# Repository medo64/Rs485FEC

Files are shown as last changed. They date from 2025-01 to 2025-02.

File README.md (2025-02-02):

[RS-485 Framework Expansion Card](https://medo64.com/rs485framecard/)
=====================================================================

This Framework laptop expansion card will show up on your system as a serial
device and allow for non-isolated RS-485 communication up to 3,000,800 baud
rate.

Please note that this card is using automatic transmit control and is 120Ω
terminated.

## Pinout

To connect to this board, one has to use a 4-pin JST XH connector. The following
table represents the pinout, pin 1 being on the left as looking into the
expansion card.

| # | Ref | Description |
|--:|-----|---|
| 1 | GND | Ground connection |
| 2 | A | Negative (low for logic 1 and high for logic 0) |
| 3 | B | Positive (high for logic 1 and low for logic 0) |
| 4 | 5V  | 100 mA power supply |

As power consumption is low, wires can be almost any AWG. I would recommend
using 24 AWG wire 0.25 mm² as they allow for greater compatibility with other
connectors.

## Supported Speeds

This board employs the FT232R as its UART chip, and consequently, it supports
all the baud rates this chip [can handle](https://ftdichip.com/Documents/AppNotes/AN232B-05_BaudRates.pdf)
up to 500,000 baud which is the limit of isolator chip used. The table below
lists the standard baud rates.

| Baud rate | Actual | Error | Divisor |
|---:|---:|---:|---:|
| 300 | 300 | 0.00% |  10000.000 |
| 600 | 600 | 0.00% | 5000.000 |
| 1,200 | 1,200 | 0.00% | 2500.000 |
| 1,800 | 1,800 | 0.00% | 1666.625 |
| 2,400 | 2,400 | 0.00% | 1250.000 |
| 4,800 | 4,800 | 0.00% | 625.000 |
| 7,200 | 7,201 | 0.01% | 416.625 |
| 9,600 | 9,600 | 0.00% | 312.500 |
| 14,400 | 14,406 | 0.04% | 208.250 |
| 19,200 | 19,200 | 0.00% | 156.250 |
| 28,800 | 28,812 | 0.04% | 104.125 |
| 38,400 | 38,400 | 0.00% | 78.125 |
| 57,600 | 57,692 | 0.16% | 52.000 |
| 115,200 | 115,385 | 0.16% | 26.000 |
| 230,400 | 230,769 | 0.16% | 13.000 |
| 460,800 | 461,538 | 0.16% | 6.500 |
| 921,600 | 923,077 | 0.16% | 3.250 |
| 1,000,000 | 1,000,000 | 0.00% | 3.000 |
| 2,000,000 | 2,000,000 | 0.00% | 2.000 |
| 3,000,000 | 3,000,000 | 0.00% | 0.000 |

While rates above this can be set, they are not guaranteed to work.

---
*You can check my blog and other projects at [www.medo64.com](https://www.medo64.com/electronics/).*

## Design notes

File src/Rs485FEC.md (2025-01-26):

### Rs485FEC

#### Parts

|  # | Part | RefDes  | Preferred Part Number |
|---:|---|---|---|
|  1 | C 10nF X7R 16V (0805) | C1 | 399-17617-1-ND |
|  5 | C 100nF X7R 16V (0805) | C2-C6 | 478-5311-1-ND |
|  3 | C 10uF X5R 16V (0805) | C7-C9 | 490-18664-1-ND |
|  1 | D Schottky 30V 800mA [CUS08F30,H3F] (SOD323) | D1 | CUS08F30H3FCT-ND |
|  1 | D TVS SM712 | D2 | SM712-TPMSCT-ND |
|  2 | DS LED (0805) | DS1-DS2 | 475-1415-1-ND |
|  1 | J USB C, plug, straddle 0.8mm | J1 | WM12855-ND |
|  1 | J JST XH Vertical (4w) | J2 | 455-B4B-XH-A-ND |
|  1 | L Ferrite 600R@100Mhz | L1 | 240-2390-1-ND |
|  1 | Q P-MOSFET DMP3099L-13 (SOT23) | Q1 | DMP3099L-13DICT-ND |
|  1 | R 120 0.125W (0805) | R1 | RMCF0805FT120RCT-ND |
|  2 | R 1K 0.125W (0805) | R2-R3 | RMCF0805FT1K00CT-ND |
|  1 | R 5.1K 0.125W (0805) | R4 | RMCF0805FT5K10CT-ND |
|  1 | R 10K 0.125W (0805) | R5 | RMCF0805FT10K0CT-ND |
|  1 | R 75K 0.125W (0805) | R6 | RMCF0805FT75K0CT-ND |
|  1 | U FT232R (SSOP-28) | U1 | 768-FT232RNL-TUBE-ND |
|  1 | U SP485EEN (SOIC-8) | U2 | 1016-1171-5-ND |
|  1 | U LoadSwitch Adjustable [AP22652W6-7] (SOT23-6) | U3 | 31-AP22652W6-7CT-ND |
|  2 | H Screw M2x3mm | - | - |

#### Specifications

| Property | Value |
|---|---|
| PCB size | 24.0 x 27.9 x 0.8 mm (1.1 in²) |
| Voltage (in) | 5 V ±10% |
| Current (in) | 500 mA (max) |
| Voltage (out) | 5 V ±15% |
| Current (limit) | 400 mA ±10% |

#### FTDI Configuration

| Setting | Value  |
|---|---|
| CBUS0 | TXLED# |
| CBUS1 | RXLED# |
| CBUS2 | TXDEN  |
| CBUS3 | PWREN# |
| CBUS4 | SLEEP# |

#### Power

| Property | Value  |
|---|---:|
| Voltage  | 5 V |
| Current  | 100 mA |

#### Termination

To remove termination, desolder termination resistor on top of the board (marked
`TERM`).

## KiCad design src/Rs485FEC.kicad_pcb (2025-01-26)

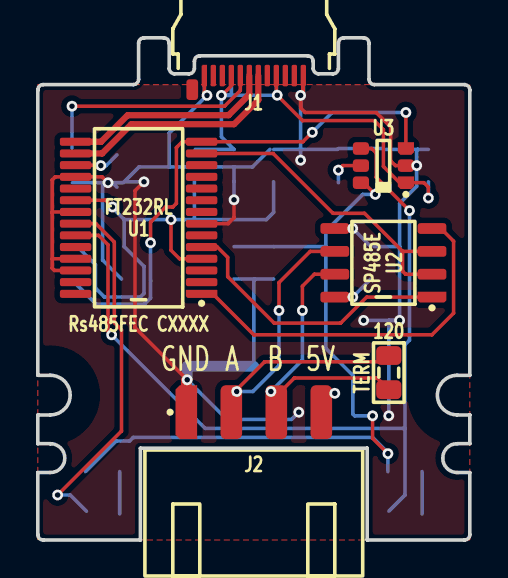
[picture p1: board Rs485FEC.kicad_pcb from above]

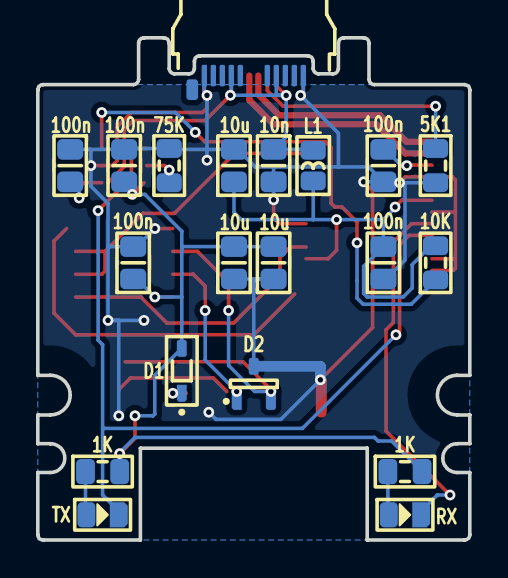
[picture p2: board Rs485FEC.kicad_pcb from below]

Board: 2 copper layers, 24.0 x 27.9 mm, 25 parts (19 on the bottom side), 20 nets.

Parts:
C1: 10n; C (0805)
C2, C3, C4, C5, C6: 100n; C (0805)
C7, C8, C9: 10u; C (0805)
D1: CUS08F30; D (SOD323)
D2: SM12T1G; D TVS 7-12V [SM712] (SOT23-3)
DS1: RX; DS (0805)
DS2: TX; DS (0805)
J1: 105444-0001; J USB C 3.2 Edge (24w)
J2: B4B-XH-A; J JST XH Edge [RS485] (4w)
L1: 600R; L (0805)
R1: 120; R (0805)
R2, R3: 1K; R (0805)
R5: 5K1; R (0805)
R5#2: 10K; R (0805)
R6: 75K; R (0805)
U1: FT232RL; U Transceiver UART [FT232R] (SSOP-28)
U2: SP485E; U Transciever RS485 [SP485EEN] (SOIC-8)
U3: AP22652; U LoadSwitch Adjustable [AP22652W6-7] (SOT23-6)

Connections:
3V3_UART_USB: C3.2, U1.17
5V: C2.2, C7.2, L1.1, R5#2.1, U1.4, U1.20
5V_OUT: D1.1, J2.4
5V_SWITCHED: C4.2, C6.1, C8.1, C9.1, D1.2, R2.1, R3.1, U2.8, U3.6
5V_USB: C1.2, C5.1, J1.A4, J1.A9, J1.B04, J1.B09, L1.2, U3.1
A: D2.2, J2.2, R1.1, U2.6
A_CC: J1.A5, R5.2
B: D2.1, J2.3, R1.2, U2.7
GND: C1.1, C2.1, C3.1, C4.1, C5.2, C6.2, C7.1, C8.2, C9.2, D2.3, J1.A1, J1.A12, J1.B01, J1.B12, J2.1, R5.1, R6.2, U1.7, U1.18, U1.21, U1.25, U1.26, U2.5, U3.2
ILIMIT: R6.1, U3.5
LED_RXD: DS1.1, U1.22
LED_RXD': DS1.2, R2.2
LED_TXD: DS2.1, U1.23, U3.4
LED_TXD': DS2.2, R3.2
PWREN#: R5#2.2, U1.14, U3.3
RXD: U1.5, U2.1
TXD: U1.1, U2.4
TXDEN: U1.13, U2.2, U2.3
USB_DM: J1.A7, U1.16
USB_DP: J1.A6, U1.15

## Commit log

2022-08-22 Move diodes a bit
2022-08-22 Fixed zener diode
2022-10-08 Added power saving circuit to FTDI variant
2022-10-08 Added extra capacitor
2022-11-07 USB VID/PID allocation
2023-11-04 Updated for KiCAD version
    [Rs485FEC.kicad_pcb]
2023-11-04 Added RTS/CTS loopback
    [Rs485FEC.kicad_pcb]
2023-11-12 Refactoring directories
    [Rs485FEC.kicad_pcb]
2023-11-12 Fixed TXDEN signal
    [Rs485FEC.kicad_pcb]
2023-11-12 Added back fail-safe biased termination
    [Rs485FEC.kicad_pcb]
2023-11-13 Removed fail-safe termination
    [Rs485FEC.kicad_pcb]
2023-11-13 Moving LEDs to bottom
    [Rs485FEC.kicad_pcb]
2023-11-13 Moved termination resistor
    [Rs485FEC.kicad_pcb]
2023-12-26 Added PWREN pullup and moved LED 5V to switched
    [Rs485FEC.kicad_pcb]
2023-12-26 Removed internal RTS/CTS connection
    [Rs485FEC.kicad_pcb]
2023-12-29 Updated connector to solder all 4 pins
    [Rs485FEC.kicad_pcb]
2023-12-30 Refactoring copper pour
    [Rs485FEC.kicad_pcb]
2024-01-31 Moved board RefDes to top
    [Rs485FEC.kicad_pcb]
2024-04-02 Updated connector designators
    [Rs485FEC.kicad_pcb]
2024-06-10 Updated for KiCAD 8
    [Rs485FEC.kicad_pcb]
2024-06-10 Added current limiting
    [Rs485FEC.kicad_pcb]
2025-01-26 Fixed refdes
    [Rs485FEC.kicad_pcb]
